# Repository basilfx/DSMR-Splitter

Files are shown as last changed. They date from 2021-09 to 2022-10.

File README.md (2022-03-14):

# DSMR Splitter
Active port expander for the P1 port on a Dutch Smart Meter (DSMR).

## Introduction
This is an active port expander for DSMR 5.0. Contrary to simple splitting
cables, this exapander buffers telegrams, and provides a dedicated port to
connected devices.

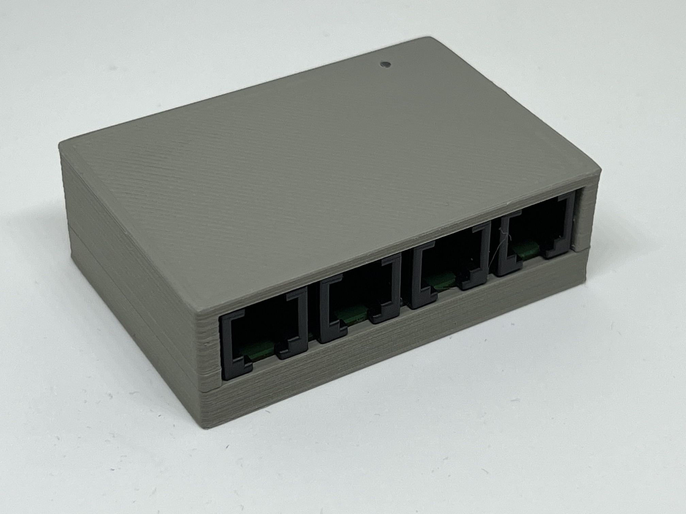
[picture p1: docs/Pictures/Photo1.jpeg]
Enclosed splitter.
[](docs/Pictures/Photo1.jpeg)
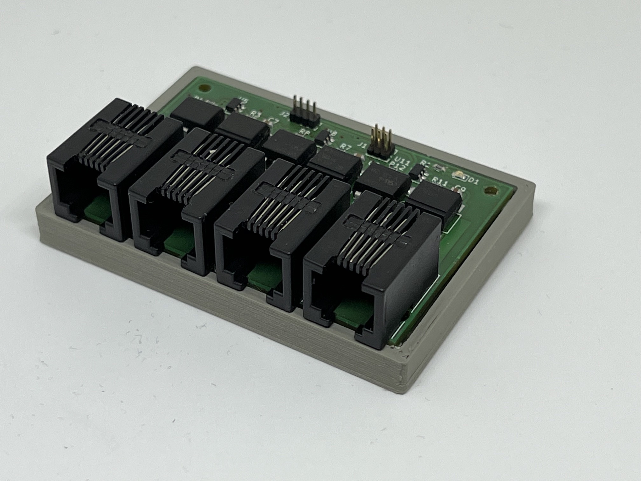
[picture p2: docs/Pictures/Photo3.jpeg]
Enclosure removed facing front-side.
[](docs/Pictures/Photo3.jpeg)
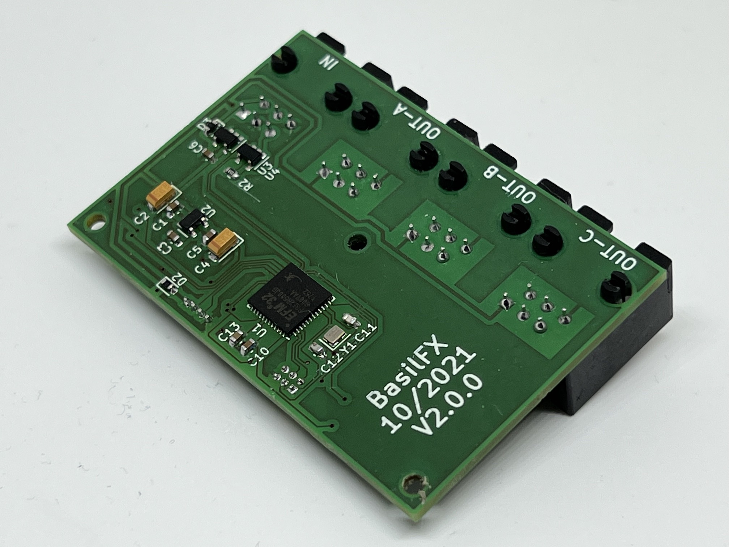
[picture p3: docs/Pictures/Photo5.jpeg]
Bottom side of the PCB.
[](docs/Pictures/Photo5.jpeg)

### Advantages
This design solves two (potential) issues compared to other splitters:

* Some port splitters have a primary and a secondary port. Only the primary
  port has the data-request line connected to the DSMR. This means that the
  secondary port cannot request telegrams on its own and depends on the device
  connected to the master port.
* A device connected to the secondary port could receive out-of-sync, if it
  depends on the data-request line. This could lead to incomplete/corrupt
  telegrams.

See [this](docs/Problem-statement.md) for more information.

## Features
* 3-port splitter.
* DSMR 5.0.
* No external power supply needed.

The splitter provides galvanic isolation between ports, if the 5 V is not used.
To read more on how this was achieved, see [this](docs/Isolation.md).

Furthemore, it requires a DSMR 5.0 meter because it provides 5 V power. Do note
that the power (5 V, 250 mA) provided by the DSMR has to be shared among all
readers, and the splitter itself requires ~50 mA.

Older DSMR versions can be supported by changing the firmware and providing 5 V
externally.

## Contents
* The `3d/` folder contains a 3D-printable design for an enclosure.
* The `firmware/` folder contains the RIOT-OS firmware used for the
  microcontroller.
* The `pcb/` folder contains the Kicad schema and board design.
* The `tools/` folder contains additional tools, such as a DSMR simulator.

## License
The work in this repository is covered by CC BY-NC-SA 4.0. See the `LICENSE.md`
file for more information.

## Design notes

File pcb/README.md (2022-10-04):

# DSMR Splitter

## Features
* ARM Cortex M4 CPU with 1 MiB of flash and 256 KiB of RAM.
* 3 isolated output ports.
* Status LED.

## Board
Top layer
Bottom layer

## Schema
You can find the schema [here](DSMR-Splitter.pdf).

## BoM
The (interactive) BoM can be found [here](https://basilfx.github.io/DSMR-Splitter/pcb/BoM/ibom.html).

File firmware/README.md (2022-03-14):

# Firmware

## Introduction
Support for DSMR is not added to RIOT-OS (yet). It lives in a separate branch
that can be found [here](https://github.com/basilfx/RIOT/tree/feature/dsmr).

To compile, navigate to the `examples/dsmr_splitter` folder, and run:

```
BOARD=dsmr_splitter make flash
```

This will compile the firmware, and flash it to the board using J-Link.

## Features
The firmware is quite extensive: it reads telegrams at a rate of 1 telegram
per second from the DSMR. It then copies the telegram to the next available
buffer of all three output ports.

This means that every output port has its own set of buffers. A buffer is
locked for reading when data is requested, but the next buffer will be written
to when a new telegram is recevied by the receiver thread.

The status LED will blink for every received telegram, but also for every
requested telegram.

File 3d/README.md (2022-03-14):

# DSMR Splitter

## Pictures
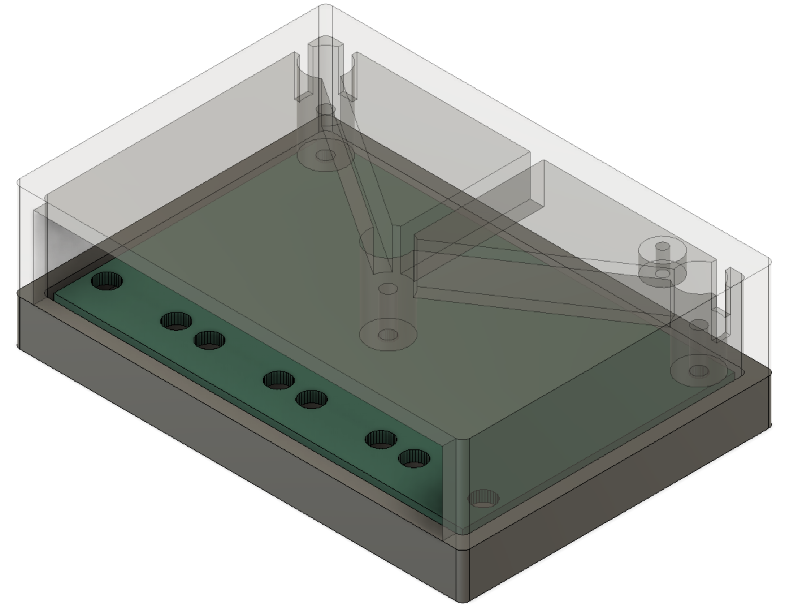
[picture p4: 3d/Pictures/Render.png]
3D render of the enclosure.
[](Pictures/Render.png)

## Dimensions
The enclosure measures approximately 66 x 46 x 21 mm.

## Print Settings
Print both parts in PETG at 0.2 mm layer height with 20% infill. Both parts can
be clamped together with M3x10 mm or M3x15 mm self-tappening screws.

## Post processing
The screws can be sunken into the part. You might need to carefully drill the
holes to match your screws.

A small hole can be drilled for the light tube. A small piece of transparant
plastic can be used, e.g. 1.75 mm transparant filmanet.

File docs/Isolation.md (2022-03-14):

# Isolation

## Introduction
All of the three ports are galvanic isolated using optocouplers, unless the
ports are connected to devices that require 5 V power supply. In that case,
the input 5 V would be connected to the output devices.

Note that optocouplers generally provide much greater galvanic isolation (order
of kilovolts). However, the distance between the pins of the RJ12 connectors is
much smaller than the distance between the input and output pins of the
optocuoplers.

## Optocoupler
To achieve the high baud rate of 115200, a high-speed optocoupler is used. This
optocoupler required 5 V, but that is not available on the output side. To make
this work, the data-request line is used as a power supply: according to the
DSMR 5.0 specification, it must be able to source 10 mA at 5 V, and it must be
toggled high before any data is transmitted.

The Vishay VOH1016A optocoupler was selected after careful testing. Its power
consumption is approximately 5 mA, which is less than the maximum of 10 mA. The
schematic below shows the schematic for one of the three output ports.

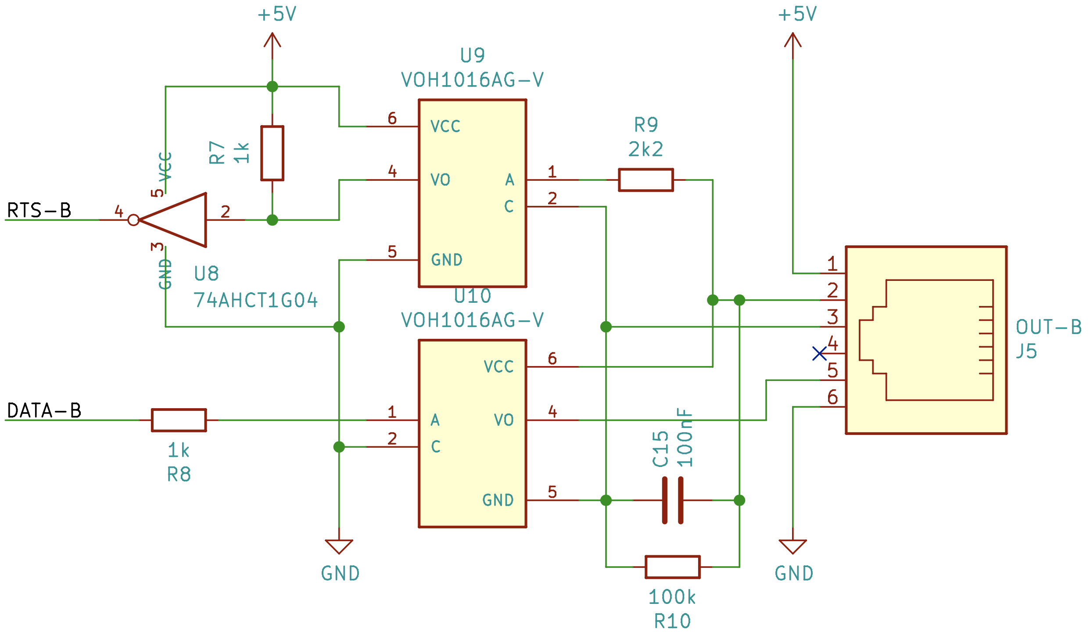
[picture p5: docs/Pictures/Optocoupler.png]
The problem statement.
[](Pictures/Optocoupler.png)

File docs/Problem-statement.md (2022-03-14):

# Problem statement

## Introduction
Given two or more readers that are connected to the DSMR. Both readers have
their own data-request line, but the data output is shared.

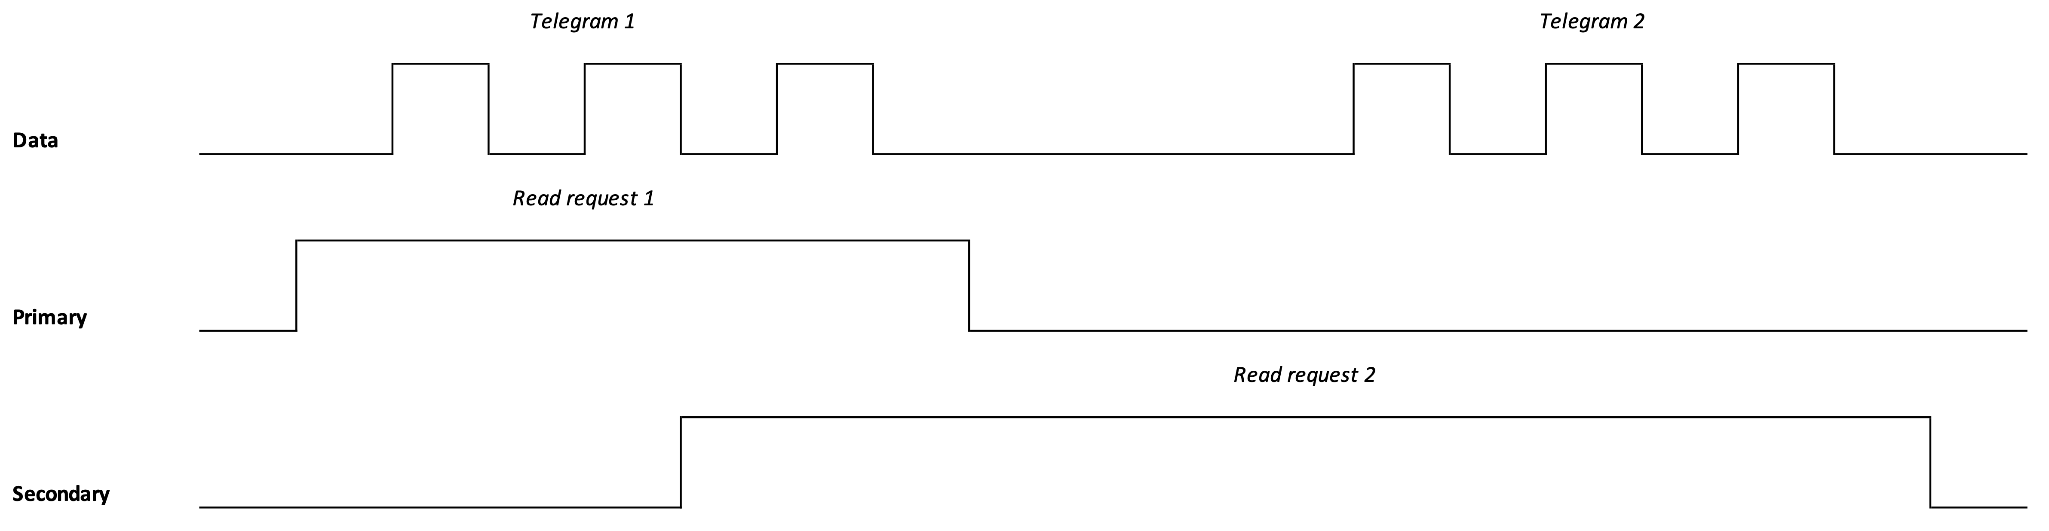
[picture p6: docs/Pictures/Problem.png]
The problem statement.
[](Pictures/Problem.png)

If the secondary port starts reading, by toggling the read request, while the
primary is still busy, the secondary will read an incomplete and invalid
telegram. Furthermore, it has to wait ~1 second before the second telegram is
outputted by the DSMR.

If the secondary port did not have the data-request line connected, it would
not been able to read a complete and valid telegram.

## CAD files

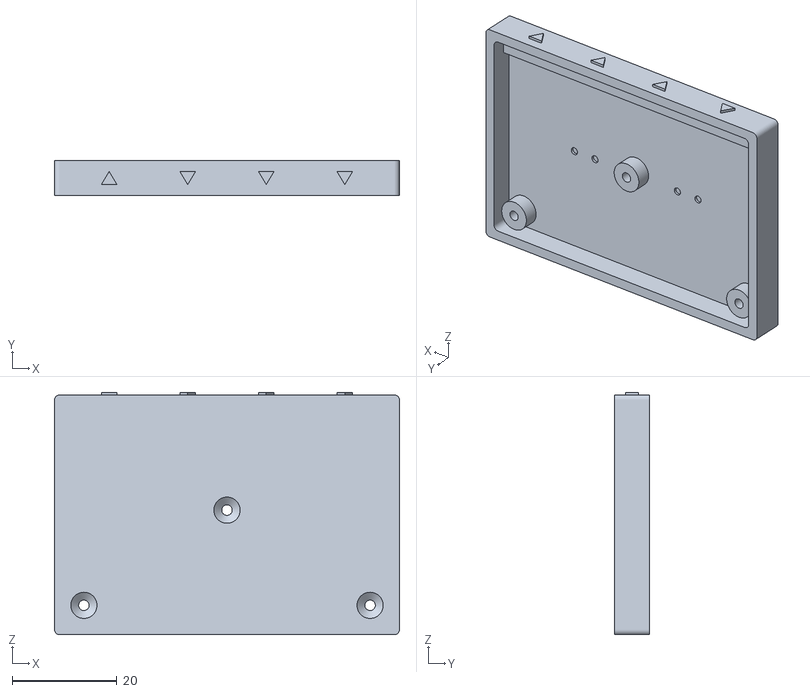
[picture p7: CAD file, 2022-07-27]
3d/Bottom_Arrows.stl
65.8 x 6.60 x 46.3

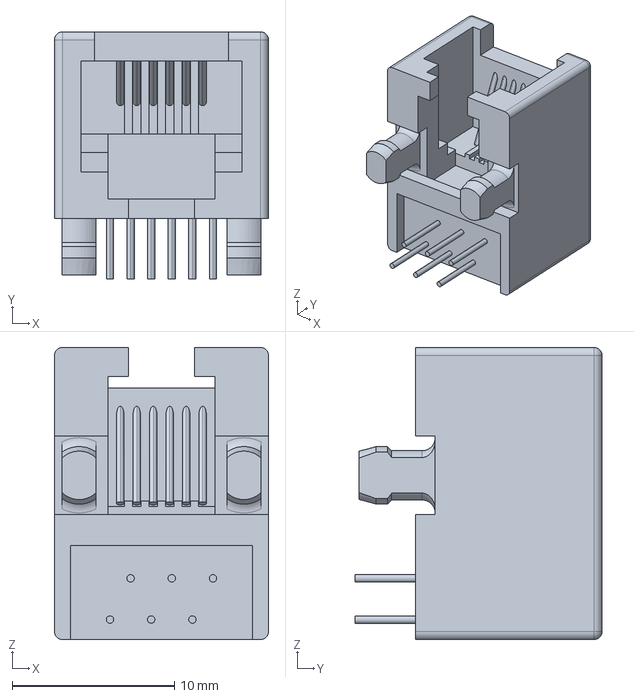
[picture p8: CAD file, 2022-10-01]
pcb/3D/Amphenol-54601-906WPLF.step
13.2 x 15.2 x 18.0 mm

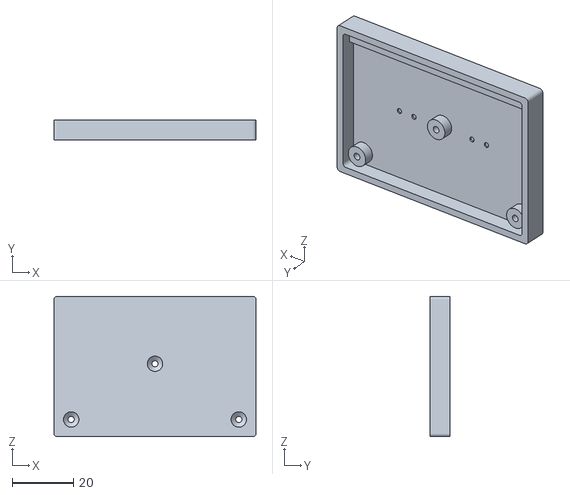
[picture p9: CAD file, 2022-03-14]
3d/Bottom.stl
65.8 x 6.60 x 45.8

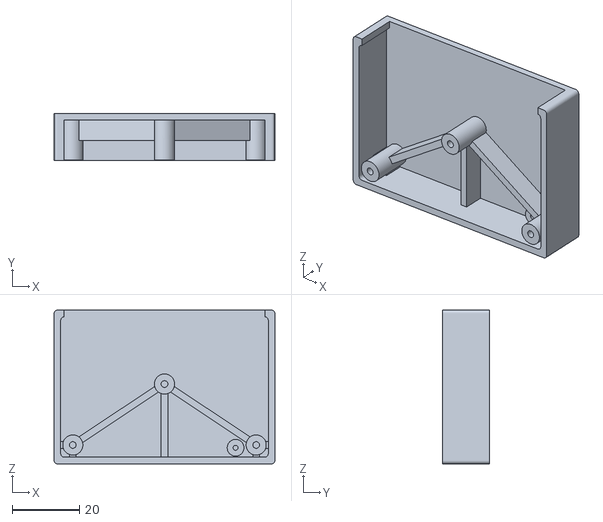
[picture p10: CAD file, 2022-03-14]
3d/Top.stl
65.8 x 14.0 x 45.8

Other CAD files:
3d/Enclosure.step

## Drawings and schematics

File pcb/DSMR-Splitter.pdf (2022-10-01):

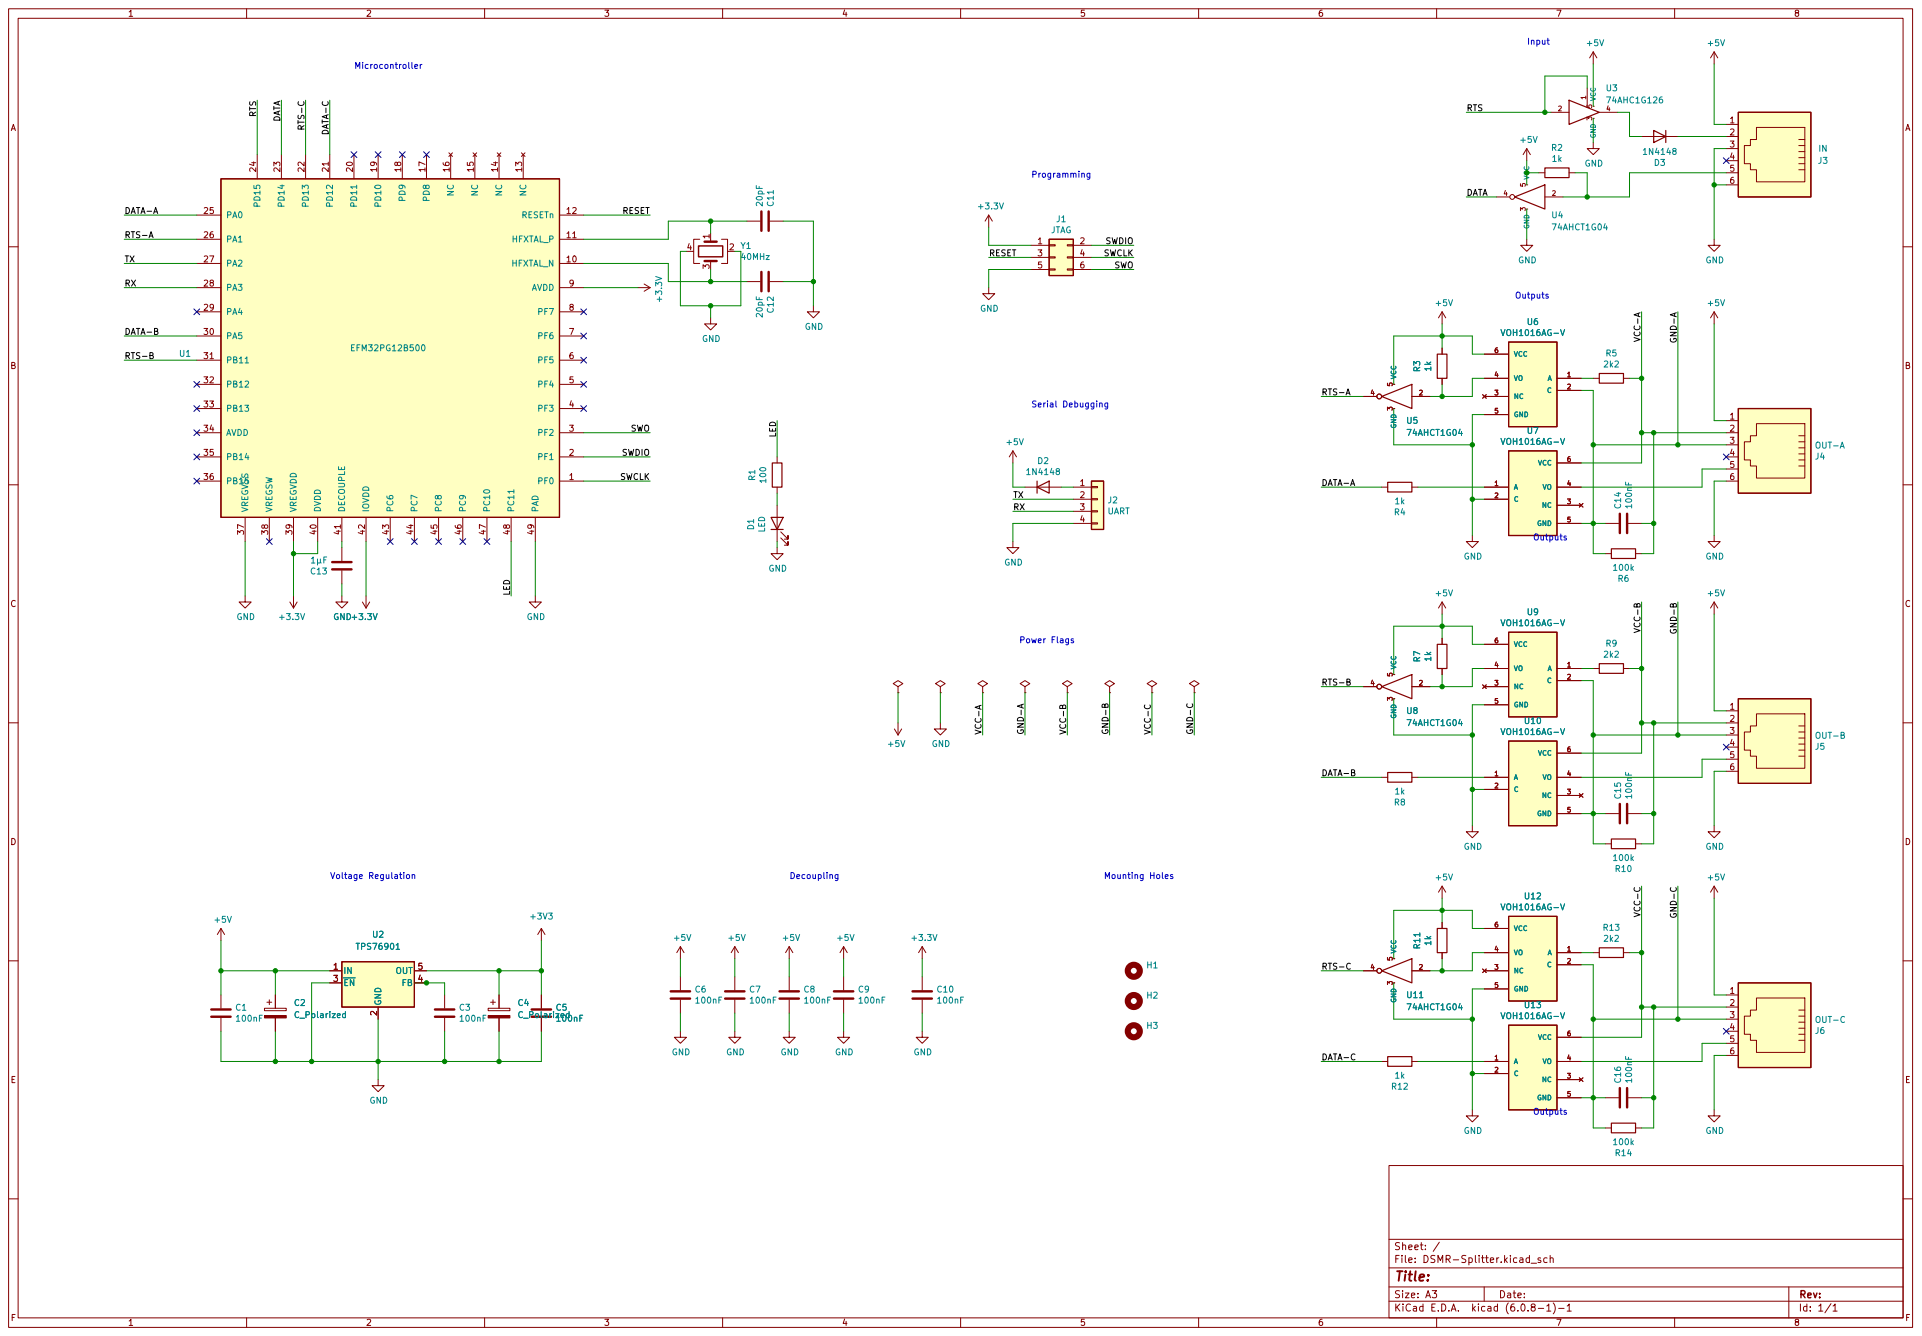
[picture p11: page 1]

File: DSMR-Splitter.kicad_sch Sheet: /

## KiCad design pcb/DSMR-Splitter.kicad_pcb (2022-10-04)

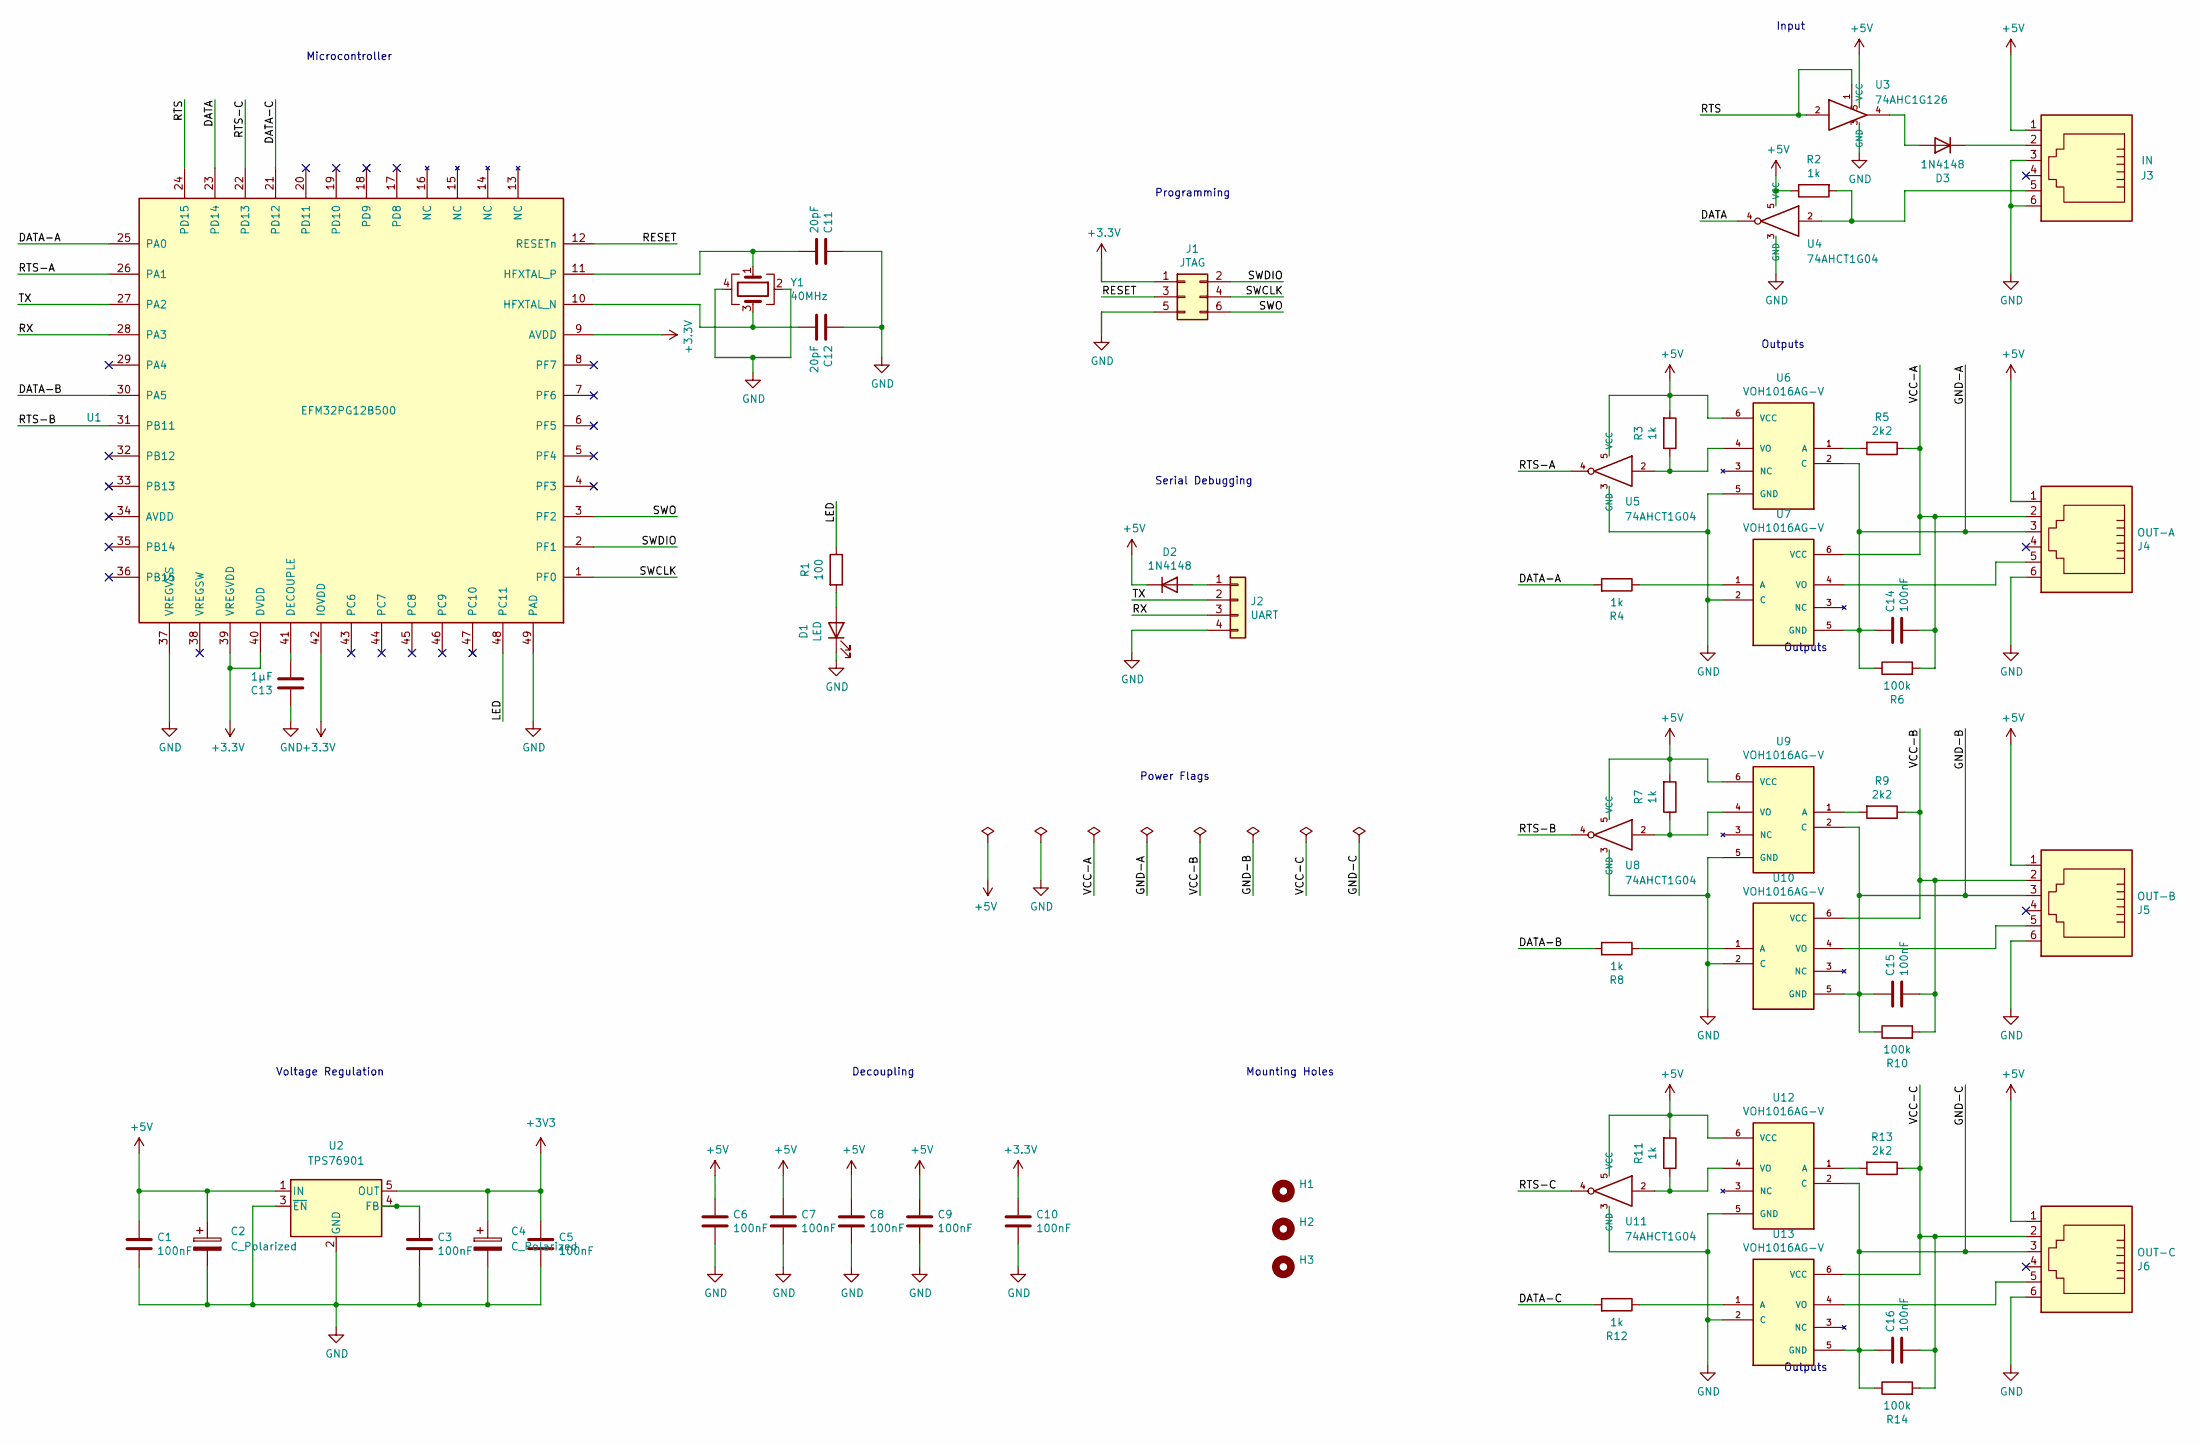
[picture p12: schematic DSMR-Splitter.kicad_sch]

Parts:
C1, C3, C5, C6, C7, C8, C9, C10, C14, C15, C16: 100nF; C_0603_1608Metric
C2, C4: C_Polarized; CP_EIA-3216-12_Kemet-S
C11, C12: 20pF; C_0603_1608Metric
C13: 1µF; C_0603_1608Metric
D1: LED; LED_0603_1608Metric
D2, D3: 1N4148; D_0603_1608Metric
H1, H2, H3: MountingHole; MountingHole_2.2mm_M2
J1: JTAG; PinHeader_2x03_P1.27mm_Vertical
J2: UART; PinHeader_1x04_P1.27mm_Vertical
J3: IN; RJ12_Amphenol_54601
J4: OUT-A; RJ12_Amphenol_54601
J5: OUT-B; RJ12_Amphenol_54601
J6: OUT-C; RJ12_Amphenol_54601
R1: 100; R_0603_1608Metric
R2, R3, R4, R7, R8, R11, R12: 1k; R_0603_1608Metric
R5, R9, R13: 2k2; R_0603_1608Metric
R6, R10, R14: 100k; R_0603_1608Metric
U1: EFM32PG12B500; QFN-48-1EP_7x7mm_P0.5mm_EP5.3x5.3mm
U2: TPS76901; SOT-23-5
U3: 74AHC1G126; SOT-23-5
U4, U5, U8, U11: 74AHCT1G04; SOT-23-5
U6, U7, U9, U10, U12, U13: VOH1016AG-V; SMDIP-6_W7.62mm; PARTREV 1.1
Y1: 40MHz; Crystal_SMD_2016-4Pin_2.0x1.6mm

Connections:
+5V: C1.1, C2.1, C6.1, C7.1, C8.1, C9.1, D2.1 (K), J3.1, J4.1, J5.1, J6.1, R2.1, R3.2, R7.2, R11.2, U2.1 (IN), U3.5 (VCC), U4.5 (VCC), U5.5 (VCC), U6.6 (VCC), U8.5 (VCC), U9.6 (VCC), U11.5 (VCC), U12.6 (VCC)
/DATA: U1.23 (PD14), U4.4
/DATA-A: R4.2, U1.25 (PA0)
/DATA-B: R8.2, U1.30 (PA5)
/DATA-C: R12.2, U1.21 (PD12)
/GND-A: C14.1, J4.3, R6.1, U6.2 (C), U7.5 (GND)
/GND-B: C15.1, J5.3, R10.1, U9.2 (C), U10.5 (GND)
/GND-C: C16.1, J6.3, R14.1, U12.2 (C), U13.5 (GND)
/LED: R1.1, U1.48 (PC11)
/RESET: J1.3, U1.12 (RESETn)
/RTS: U1.24 (PD15), U3.1, U3.2
/RTS-A: U1.26 (PA1), U5.4
/RTS-B: U1.31 (PB11), U8.4
/RTS-C: U1.22 (PD13), U11.4
/RX: J2.3, U1.28 (PA3)
/SWCLK: J1.4, U1.1 (PF0)
/SWDIO: J1.2, U1.2 (PF1)
/SWO: J1.6, U1.3 (PF2)
/TX: J2.2, U1.27 (PA2)
/VCC-A: C14.2, J4.2, R5.1, R6.2, U7.6 (VCC)
/VCC-B: C15.2, J5.2, R9.1, R10.2, U10.6 (VCC)
/VCC-C: C16.2, J6.2, R13.1, R14.2, U13.6 (VCC)
GND: C1.2, C2.2, C3.2, C4.2, C5.2, C6.2, C7.2, C8.2, C9.2, C10.2, C11.1, C12.1, C13.1, D1.1 (K), J1.5, J2.4, J3.3, J3.6, J4.6, J5.6, J6.6, U1.37 (VREGVSS), U1.49 (PAD), U2.2 (GND), U2.3 (~EN), U3.3 (GND), U4.3 (GND), U5.3 (GND), U6.5 (GND), U7.2 (C), U8.3 (GND), U9.5 (GND), U10.2 (C), U11.3 (GND), U12.5 (GND), U13.2 (C), Y1.2, Y1.4
unnamed: C3.1, U2.4 (FB)
unnamed: C11.2, U1.11 (HFXTAL_P), Y1.1
unnamed: C12.2, U1.10 (HFXTAL_N), Y1.3
unnamed: C13.2, U1.41 (DECOUPLE)
unnamed: D1.2 (A), R1.2
unnamed: D2.2 (A), J2.1
unnamed: D3.1 (K), J3.2
unnamed: D3.2 (A), U3.4
unnamed: J3.5, R2.2, U4.2
unnamed: J4.5, U7.4 (VO)
unnamed: J5.5, U10.4 (VO)
unnamed: J6.5, U13.4 (VO)
unnamed: R3.1, U5.2, U6.4 (VO)
unnamed: R4.1, U7.1 (A)
unnamed: R5.2, U6.1 (A)
unnamed: R7.1, U8.2, U9.4 (VO)
unnamed: R8.1, U10.1 (A)
unnamed: R9.2, U9.1 (A)
unnamed: R11.1, U11.2, U12.4 (VO)
unnamed: R12.1, U13.1 (A)
unnamed: R13.2, U12.1 (A)

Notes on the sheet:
Decoupling
Microcontroller
Outputs
Input
Serial Debugging
Mounting Holes
Voltage Regulation
Programming
Power Flags

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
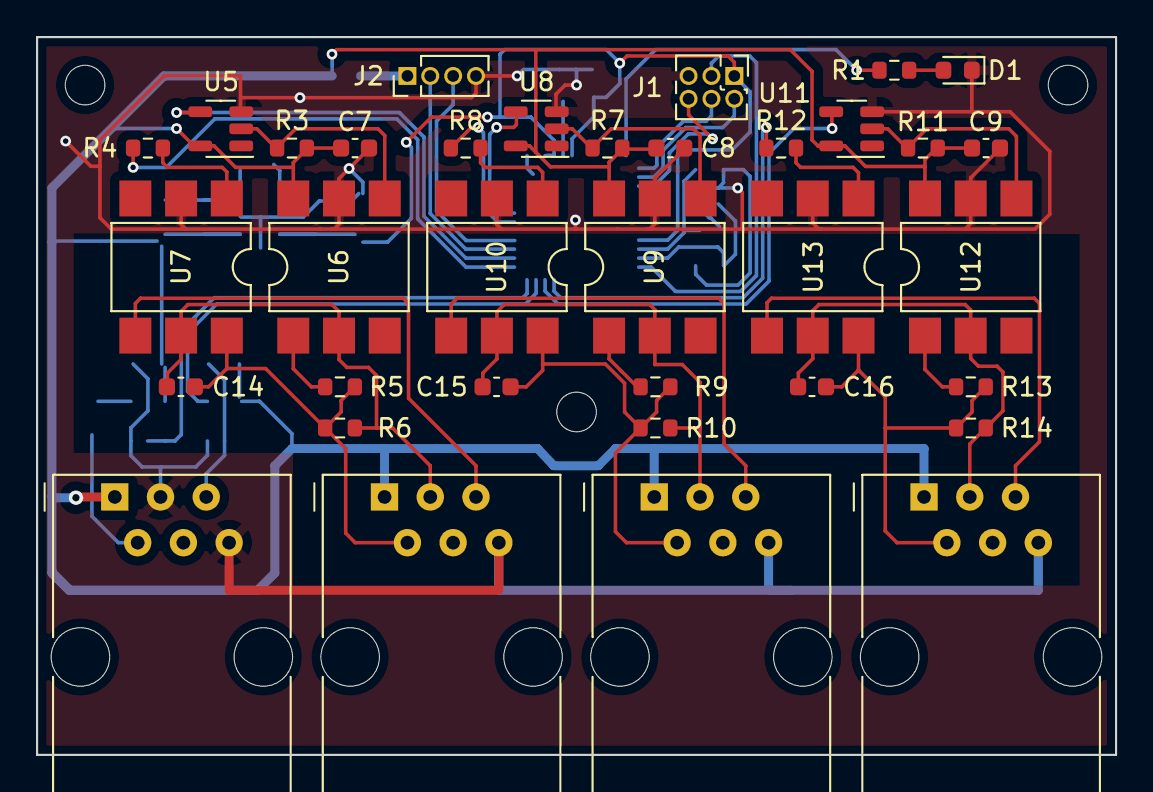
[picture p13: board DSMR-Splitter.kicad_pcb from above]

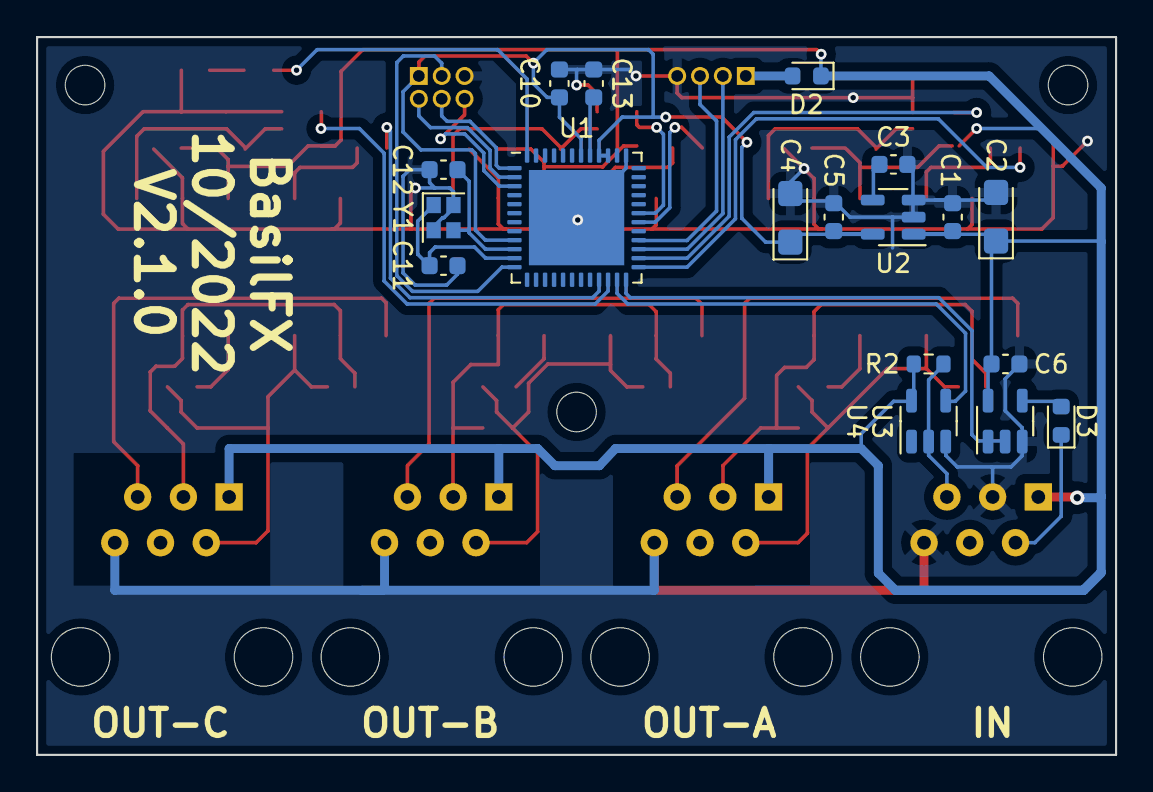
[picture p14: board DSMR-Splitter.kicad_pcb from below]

Board: 2 copper layers, 59.9 x 39.9 mm, 56 parts (18 on the bottom side), 45 nets.

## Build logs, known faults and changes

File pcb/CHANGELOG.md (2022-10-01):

# Changelog

## v2.1.0
Released 02 October 2022

Highlights:
* Changed: migrated schema + PCB to KiCad 6.0.
* Improved: 3D models.
* Fixed: several ERC and DRC errors.

## v2.0.0
Released 14 March 2022

Highlights:
* Reduced the board width by 3 mm, to ensures the RJ-12 sockets extend beyond
  the edge. This way, they fit extend more when enclosed.
* Added galvanic isolation by redesigning the board.
* Changed debug and serial headers to 1.27 mm pitch.

## v1.0.0
Released 6 September 2021

Highlights:
* Initial version.

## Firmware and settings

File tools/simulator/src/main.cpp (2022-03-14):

#include <Arduino.h>
#include <SoftwareSerial.h>

const int rxPin = 2;
const int txPin = 3;
const int rtsPin = 7;

SoftwareSerial SwSerial(rxPin, txPin, true);

unsigned char telegram[] = {
  0x2f, 0x49, 0x53, 0x6b, 0x35, 0x5c, 0x32, 0x4d, 0x54, 0x33, 0x38, 0x32,
  0x2d, 0x31, 0x30, 0x30, 0x30, 0x0d, 0x0a, 0x0d, 0x0a, 0x31, 0x2d, 0x33,
  0x3a, 0x30, 0x2e, 0x32, 0x2e, 0x38, 0x28, 0x35, 0x30, 0x29, 0x0d, 0x0a,
  0x30, 0x2d, 0x30, 0x3a, 0x31, 0x2e, 0x30, 0x2e, 0x30, 0x28, 0x31, 0x37,
  0x30, 0x31, 0x30, 0x32, 0x31, 0x39, 0x32, 0x30, 0x30, 0x32, 0x57, 0x29,
  0x0d, 0x0a, 0x30, 0x2d, 0x30, 0x3a, 0x39, 0x36, 0x2e, 0x31, 0x2e, 0x31,
  0x28, 0x34, 0x42, 0x33, 0x38, 0x34, 0x35, 0x34, 0x37, 0x33, 0x30, 0x33,
  0x30, 0x33, 0x34, 0x33, 0x30, 0x33, 0x34, 0x33, 0x36, 0x33, 0x33, 0x33,
  0x39, 0x33, 0x35, 0x33, 0x35, 0x33, 0x30, 0x33, 0x37, 0x29, 0x0d, 0x0a,
  0x31, 0x2d, 0x30, 0x3a, 0x31, 0x2e, 0x38, 0x2e, 0x31, 0x28, 0x30, 0x30,
  0x30, 0x30, 0x30, 0x34, 0x2e, 0x34, 0x32, 0x36, 0x2a, 0x6b, 0x57, 0x68,
  0x29, 0x0d, 0x0a, 0x31, 0x2d, 0x30, 0x3a, 0x31, 0x2e, 0x38, 0x2e, 0x32,
  0x28, 0x30, 0x30, 0x30, 0x30, 0x30, 0x32, 0x2e, 0x33, 0x39, 0x39, 0x2a,
  0x6b, 0x57, 0x68, 0x29, 0x0d, 0x0a, 0x31, 0x2d, 0x30, 0x3a, 0x32, 0x2e,
  0x38, 0x2e, 0x31, 0x28, 0x30, 0x30, 0x30, 0x30, 0x30, 0x32, 0x2e, 0x34,
  0x34, 0x34, 0x2a, 0x6b, 0x57, 0x68, 0x29, 0x0d, 0x0a, 0x31, 0x2d, 0x30,
  0x3a, 0x32, 0x2e, 0x38, 0x2e, 0x32, 0x28, 0x30, 0x30, 0x30, 0x30, 0x30,
  0x30, 0x2e, 0x30, 0x30, 0x30, 0x2a, 0x6b, 0x57, 0x68, 0x29, 0x0d, 0x0a,
  0x30, 0x2d, 0x30, 0x3a, 0x39, 0x36, 0x2e, 0x31, 0x34, 0x2e, 0x30, 0x28,
  0x30, 0x30, 0x30, 0x32, 0x29, 0x0d, 0x0a, 0x31, 0x2d, 0x30, 0x3a, 0x31,
  0x2e, 0x37, 0x2e, 0x30, 0x28, 0x30, 0x30, 0x2e, 0x32, 0x34, 0x34, 0x2a,
  0x6b, 0x57, 0x29, 0x0d, 0x0a, 0x31, 0x2d, 0x30, 0x3a, 0x32, 0x2e, 0x37,
  0x2e, 0x30, 0x28, 0x30, 0x30, 0x2e, 0x30, 0x30, 0x30, 0x2a, 0x6b, 0x57,
  0x29, 0x0d, 0x0a, 0x30, 0x2d, 0x30, 0x3a, 0x39, 0x36, 0x2e, 0x37, 0x2e,
  0x32, 0x31, 0x28, 0x30, 0x30, 0x30, 0x31, 0x33, 0x29, 0x0d, 0x0a, 0x30,
  0x2d, 0x30, 0x3a, 0x39, 0x36, 0x2e, 0x37, 0x2e, 0x39, 0x28, 0x30, 0x30,
  0x30, 0x30, 0x30, 0x29, 0x0d, 0x0a, 0x31, 0x2d, 0x30, 0x3a, 0x39, 0x39,
  0x2e, 0x39, 0x37, 0x2e, 0x30, 0x28, 0x30, 0x29, 0x28, 0x30, 0x2d, 0x30,
  0x3a, 0x39, 0x36, 0x2e, 0x37, 0x2e, 0x31, 0x39, 0x29, 0x0d, 0x0a, 0x31,
  0x2d, 0x30, 0x3a, 0x33, 0x32, 0x2e, 0x33, 0x32, 0x2e, 0x30, 0x28, 0x30,
  0x30, 0x30, 0x30, 0x30, 0x29, 0x0d, 0x0a, 0x31, 0x2d, 0x30, 0x3a, 0x35,
  0x32, 0x2e, 0x33, 0x32, 0x2e, 0x30, 0x28, 0x30, 0x30, 0x30, 0x30, 0x30,
  0x29, 0x0d, 0x0a, 0x31, 0x2d, 0x30, 0x3a, 0x37, 0x32, 0x2e, 0x33, 0x32,
  0x2e, 0x30, 0x28, 0x30, 0x30, 0x30, 0x30, 0x30, 0x29, 0x0d, 0x0a, 0x31,
  0x2d, 0x30, 0x3a, 0x33, 0x32, 0x2e, 0x33, 0x36, 0x2e, 0x30, 0x28, 0x30,
  0x30, 0x30, 0x30, 0x30, 0x29, 0x0d, 0x0a, 0x31, 0x2d, 0x30, 0x3a, 0x35,
  0x32, 0x2e, 0x33, 0x36, 0x2e, 0x30, 0x28, 0x30, 0x30, 0x30, 0x30, 0x30,
  0x29, 0x0d, 0x0a, 0x31, 0x2d, 0x30, 0x3a, 0x37, 0x32, 0x2e, 0x33, 0x36,
  0x2e, 0x30, 0x28, 0x30, 0x30, 0x30, 0x30, 0x30, 0x29, 0x0d, 0x0a, 0x30,
  0x2d, 0x30, 0x3a, 0x39, 0x36, 0x2e, 0x31, 0x33, 0x2e, 0x30, 0x28, 0x29,
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
};

void setup()
{
    Serial.begin(115200);
    SwSerial.begin(115200);

    pinMode(7, INPUT);
}

void loop()
{
    long start = millis();

    if (digitalRead(rtsPin) == 1) {
        Serial.println("Telegram requested.");

        SwSerial.write(telegram, sizeof(telegram));
    }

    long end = millis();

    delay(1000 - (end - start));
}

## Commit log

2021-09-20 Initial commit.
    [Bottom.stl, DSMR-Splitter.kicad_pcb, DSMR-Splitter.sch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]
2022-03-14 Add board version 2.0.0
    [Bottom.stl, DSMR-Splitter.kicad_pcb, DSMR-Splitter.sch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]
2022-07-27 Add bottom enclosure with arrows
    [Bottom_Arrows.stl, Enclosure.step]
2022-10-01 Adapt gitignore for KiCad6
2022-10-01 Upgrade project to KiCad 6.0
    [Amphenol-54601-906WPLF.step, DSMR-Splitter.kicad_pcb, DSMR-Splitter.kicad_sch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]
2022-10-04 Replace BoM with interactive BoM
2022-10-04 Annotate schema with order numbers
    [DSMR-Splitter.kicad_pcb, DSMR-Splitter.kicad_sch]
2022-10-04 Add Tracespace board render settings
